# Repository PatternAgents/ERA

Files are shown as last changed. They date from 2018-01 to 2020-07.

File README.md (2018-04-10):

# ERA Embedded Rack Architecture 
 


This repository contains Open Source Hardware Reference Designs for the Embedded Rack Architecture (ERA),
a new design pattern for the interconnection and packaging of Modular Audio/Video equipment.

The Embedded Rack Architecture (ERA) is a new, 
Open Source Hardware (OSHW) specification for 
Modular Audio/Video equipment that is being co-developed by a number of
cooperating companies and individuals in the audio field,
and is backward compatible with the Eurorack specification (aka Legacy Eurorack). 

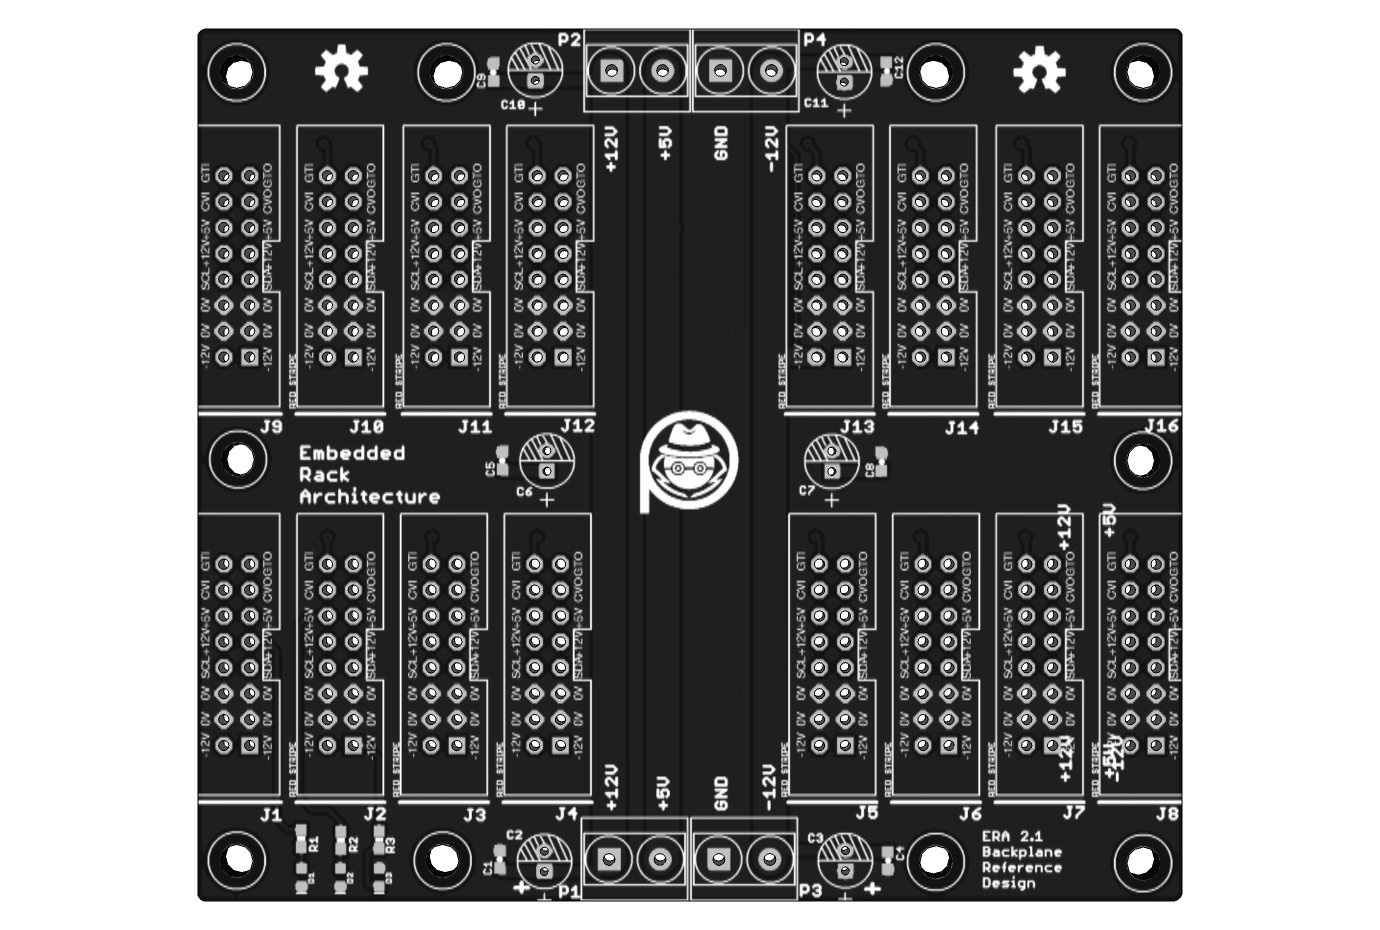
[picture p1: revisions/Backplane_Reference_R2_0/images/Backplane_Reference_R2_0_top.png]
Embedded Rack Architecture (ERA) Backplane Reference Design


For more information, please see the [ERA Wiki](https://github.com/patternagents/ERA/wiki)!

If you'd like to be involved in the development of the new 
Embedded Rack Architecture (ERA) specifications and reference designs,
then please contact us at :  [PatternAgents](https://patternagents.com/store)

-----------------------------------------------------

Eurorack (Legacy) References and Articles

[Doepfer- Eurorack ](http://www.doepfer.de/a100_man/a100m_e.htm)

[Wikipedia-Doepfer](https://en.wikipedia.org/wiki/Doepfer_A-100)

[SDIY Info](https://www.sdiy.info/w/Eurorack)

-----------------------------------------------------

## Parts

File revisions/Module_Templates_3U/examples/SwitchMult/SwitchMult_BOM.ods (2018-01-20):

Qty | Value | Device | Package | Parts | MFR Part Number
5 | 510 | RESISTORPTH-1/4W | AXIAL-0.4 | R1, R2, R3, R4, R5 | MF1/4LCT52R511J
1 | ERA-SHROUD | ERA-SHROUD | ERA | J1 | 302-S161
 | LP4EE1PBCTG | LP4EE1PBCTx | LP4EE1PBCTx | SW1 | LP4EE1PBCTx
 | LP4EE1PBCTG | LP4EE1PBCTx | LP4EE1PBCTx | SW2 | LP4EE1PBCTx
 | LP4EE1PBCTG | LP4EE1PBCTx | LP4EE1PBCTx | SW3 | LP4EE1PBCTx
5 | LP4EE1PBCTG | LLP4EE1PBCTx | LP4EE1PBCTx | SW4 | LP4EE1PBCTx
7 | PJ301_THONKICONN6 | PJ301_THONKICONN6 | WQP_PJ_301M6 | P1, P2, P3, P4, P5, P6, P7 | WQP_PJ_301M6

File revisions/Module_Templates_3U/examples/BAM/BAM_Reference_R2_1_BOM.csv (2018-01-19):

Qty | Value | Device | Package | Parts | Description | MPN | PROD_ID | VALUE
2 | 1K | RESISTOR0603 | 0603-RES | R2, R4 | Resistor
2 | 100K | RESISTOR0603 | 0603-RES | R1, R6 | Resistor
2 | 4K7 | RESISTOR0603 | 0603-RES | R3, R5 | Resistor
2 | BSS138W-7-F | SMD-MOSFET-N-CH-50V-200MA-BSS138W-7-F(SOT-23) | SOT-23 | Q1, Q2 | 305030000 | BSS138W-7-F |  | BSS138W-7-F
2 | ERA-SHROUD | ERA-SHROUD | ERA | ERA, EURO | Embedded Rack Backplane Connector
6 | JACK-3_5MM-MONO-SW-MJ_3502 | JACK-3_5MM-MONO-SW-MJ_3502 | MJ-3502 | CV_IN, CV_OUT, CV_THRU, GATE_IN, GATE_OUT, GATE_THRU | Jack, 3.5mm, RIght Angle, Though-Hole
1 | LED-RG-CC-PTH-G18500 | LED-RG-CC-PTH-G18500 | LED-RG-PANEL | LED1 | LED Red/Green Common Cathode Pin Through Hole

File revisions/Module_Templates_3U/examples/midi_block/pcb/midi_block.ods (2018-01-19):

Qty | Value | Device | Package | Parts | Description | PROD_ID
3 |  | JMP-3-NO-PTH | JMP-3-NO-PTH-2.54 | RXD, TXD, VCC | Three Terminal Jumper - Normally Open
2 | 100nf | CAP0603-CAP | 0603-CAP | C1, C3 | Capacitor
1 | 10uf | CAP0603-CAP | 0603-CAP | C2 | Capacitor
2 | 1K | R-US_R0603 | R0603 | R2, R3 | RESISTOR, American symbol
1 | 1N4148 | DIODE-SOD323-W | SOD323-W | D1 | DIODE
7 | 220 | R-US_R0603 | R0603 | R1, R4, R5, R6, R7, R8, R9 | RESISTOR, American symbol
1 | 6N137SMT | 6N137SMT | DIL8-SMD | OPTO | MOTOROLA OPTO COUPLER
1 | 74HC7014D | 74HC7014D | SOIC-14 | U1 | The 74HC7014 is a hex buffer with precision Schmitt-trigger inputs. | IC-12527
3 | DIN-5-MIDI-PTH-RA | DIN-5-MIDI-PTH-RA | DIN-5-PTH-RA-SUPPORT | MIDI_IN, MIDI_OUT, MIDI_THRU | DIN-5 (MIDI) connector
1 | ERA-SHROUD | ERA-SHROUD | ERA | ERA | EuroRack2 - Backplane Connector
1 | LED-RG-CC-PTH-G18500 | LED-RG-CC-PTH-G18500 | LED-RG-PANEL | LED1 | LED Red/Green Common Cathode Pin Through Hole
2 | MOUNT-HOLE3,2S | MOUNT-HOLE3,2S | 3,2,SMALL | H1, H2 | MOUNTING HOLE with drill center marker
1 | PA_FTDI_BASIC_PERIPHERAL | PA_FTDI_BASIC_PERIPHERAL | PA_PMOD_SIL_MALE | FTDI | PatternAgents FTDI UART BASIC Pattern
4 | PCB-MB-SIDE | PCB-MB-SIDE | PCB-MB-01-SIDE | U$1, U$2, U$3, U$4 | Mounting Block Hardware

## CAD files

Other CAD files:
revisions/Module_Templates_3U/examples/BAM/eagleUp/BAM_Reference_R2_1.skp
revisions/Module_Templates_3U/examples/SwitchMult/eagleUp/SwitchMult.skp
revisions/Module_Templates_3U/examples/midi_block/pcb/eagleUp/midi_block.skp

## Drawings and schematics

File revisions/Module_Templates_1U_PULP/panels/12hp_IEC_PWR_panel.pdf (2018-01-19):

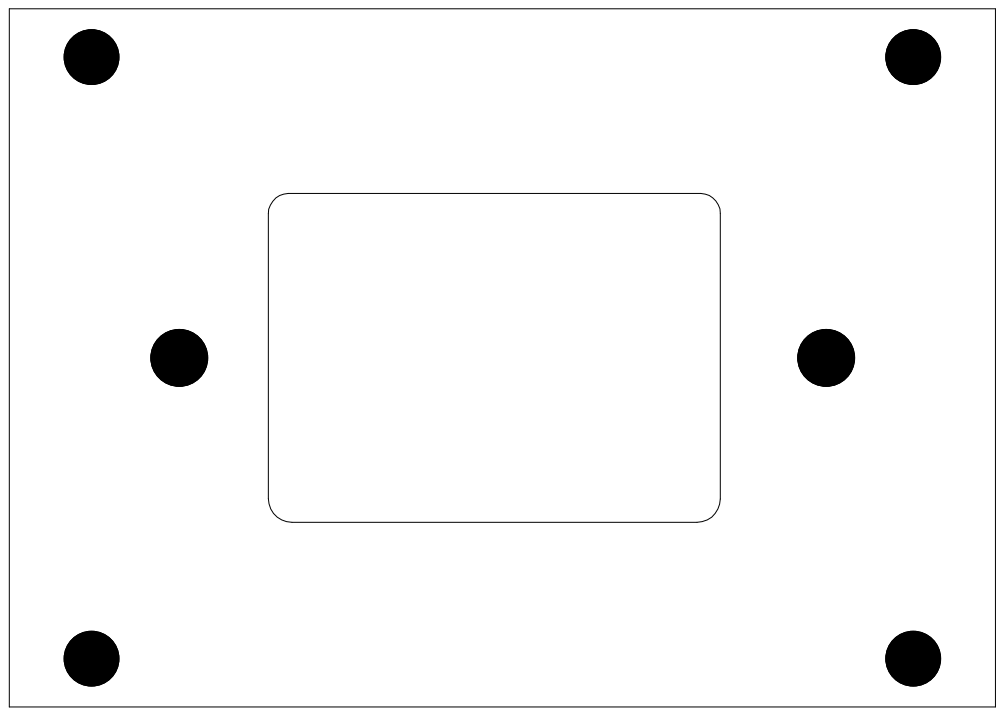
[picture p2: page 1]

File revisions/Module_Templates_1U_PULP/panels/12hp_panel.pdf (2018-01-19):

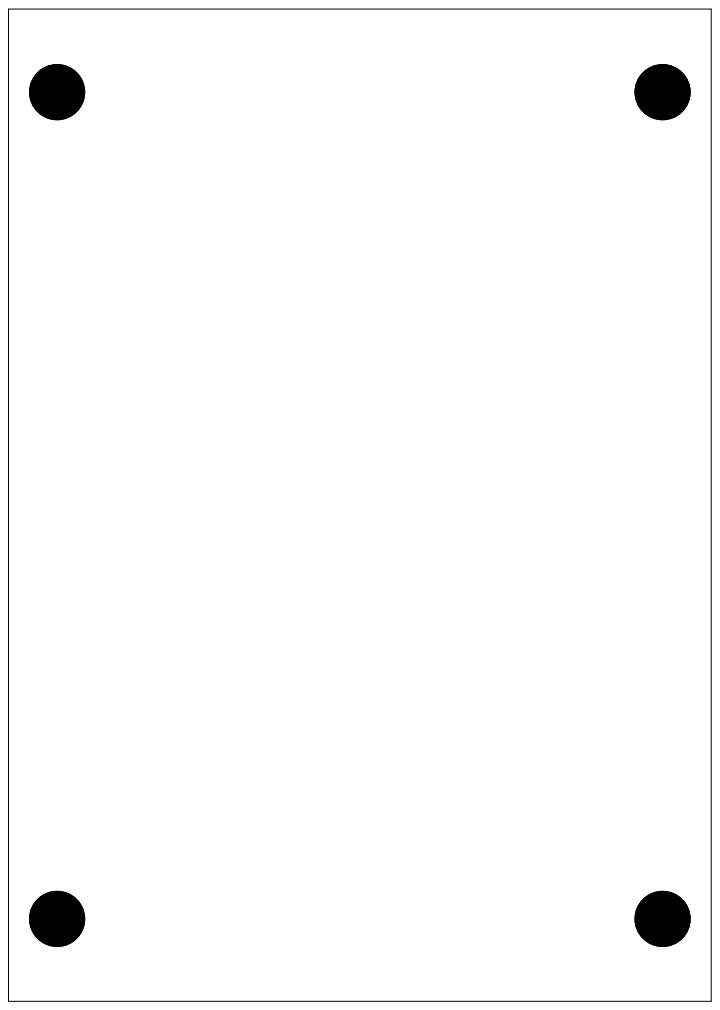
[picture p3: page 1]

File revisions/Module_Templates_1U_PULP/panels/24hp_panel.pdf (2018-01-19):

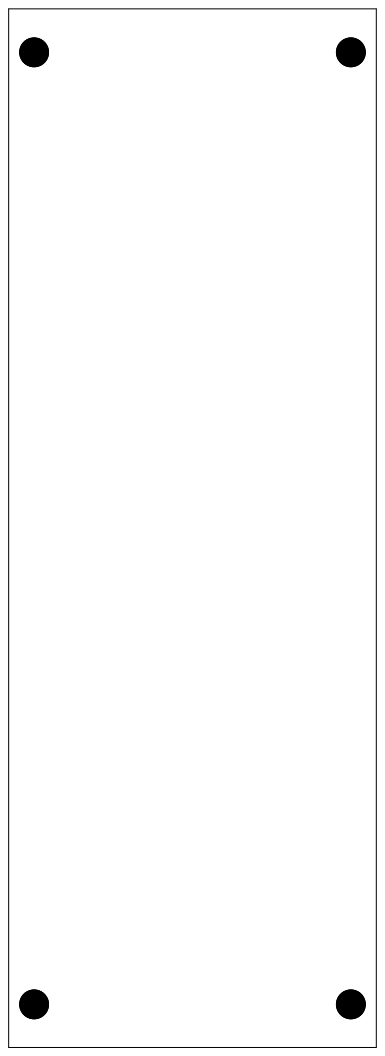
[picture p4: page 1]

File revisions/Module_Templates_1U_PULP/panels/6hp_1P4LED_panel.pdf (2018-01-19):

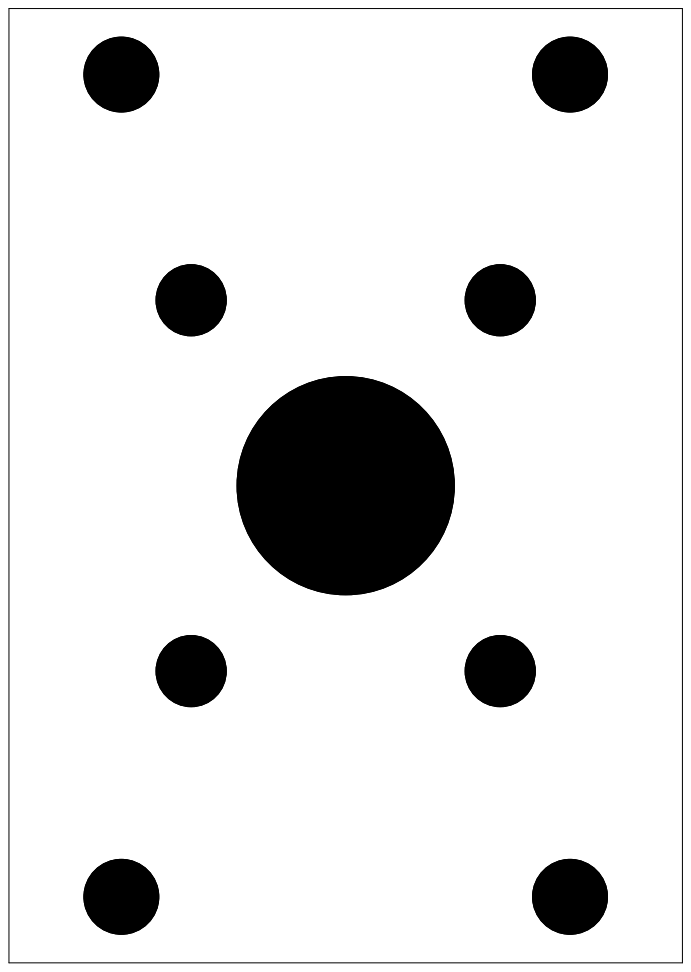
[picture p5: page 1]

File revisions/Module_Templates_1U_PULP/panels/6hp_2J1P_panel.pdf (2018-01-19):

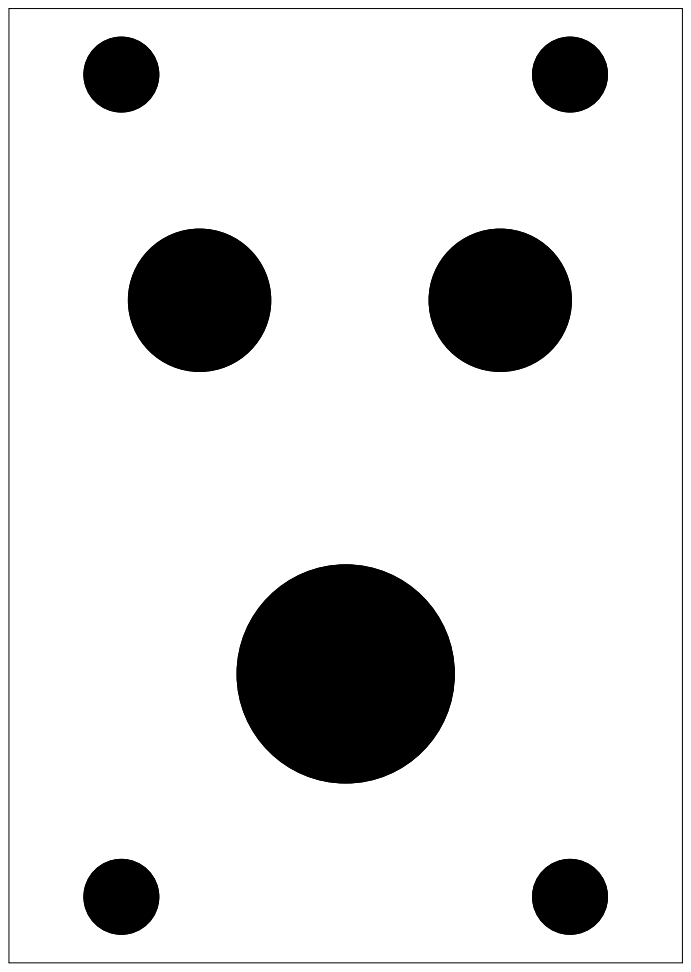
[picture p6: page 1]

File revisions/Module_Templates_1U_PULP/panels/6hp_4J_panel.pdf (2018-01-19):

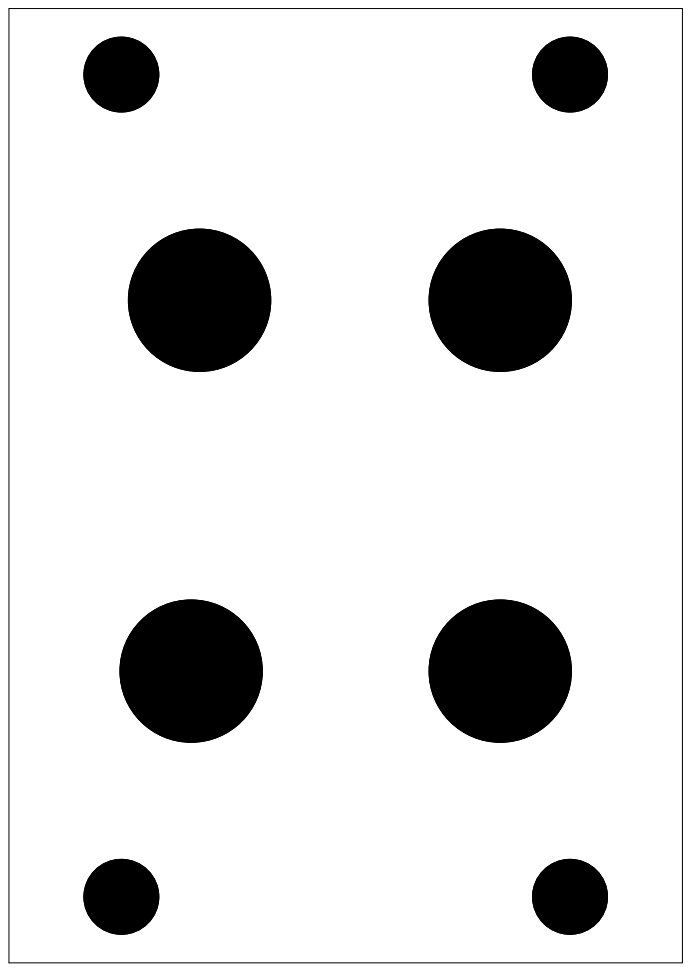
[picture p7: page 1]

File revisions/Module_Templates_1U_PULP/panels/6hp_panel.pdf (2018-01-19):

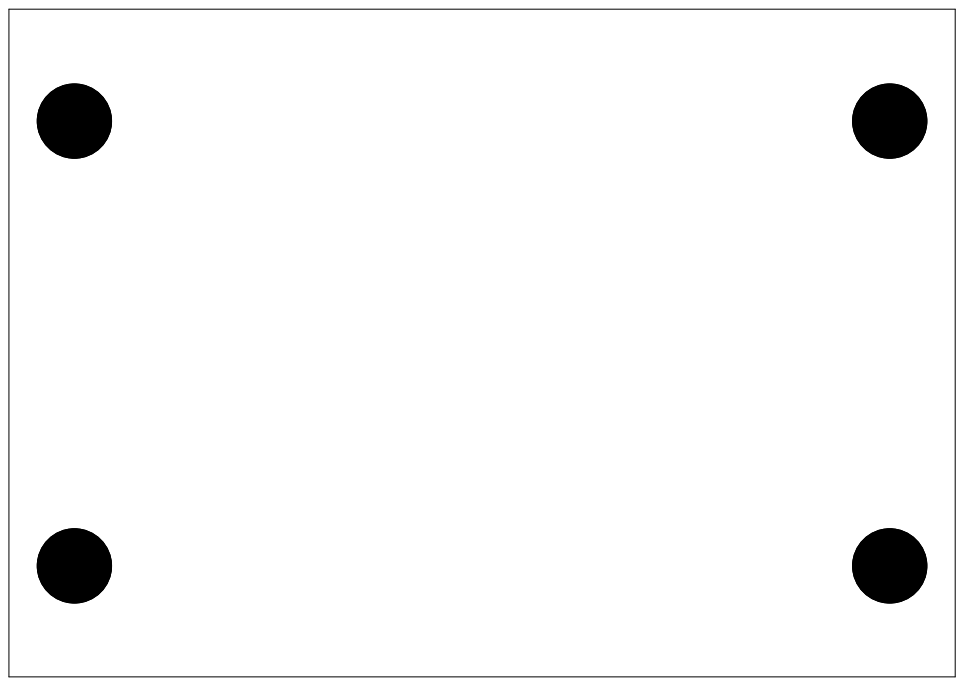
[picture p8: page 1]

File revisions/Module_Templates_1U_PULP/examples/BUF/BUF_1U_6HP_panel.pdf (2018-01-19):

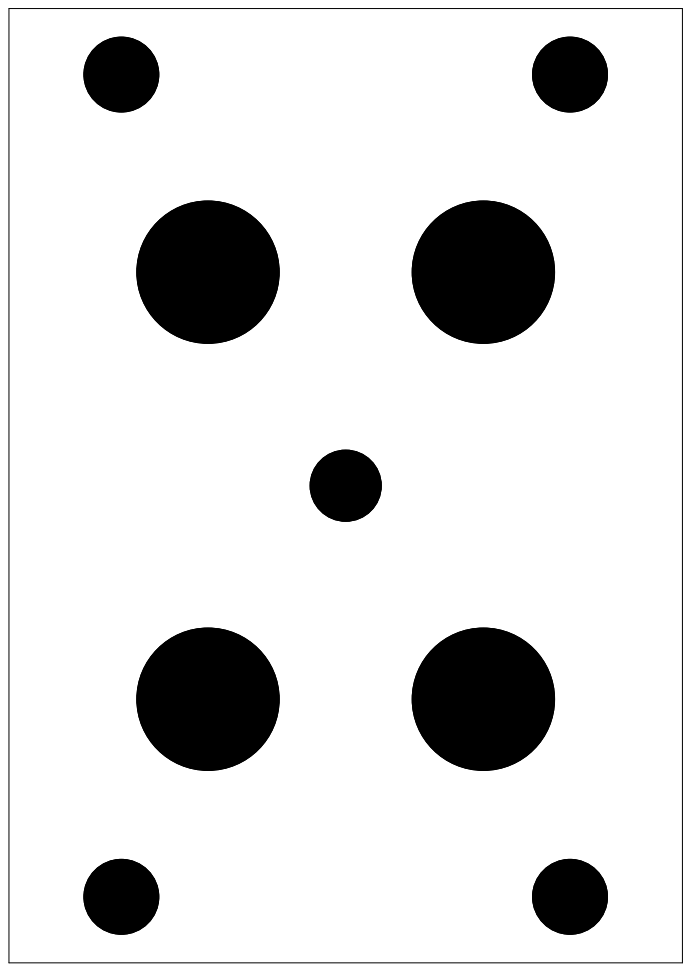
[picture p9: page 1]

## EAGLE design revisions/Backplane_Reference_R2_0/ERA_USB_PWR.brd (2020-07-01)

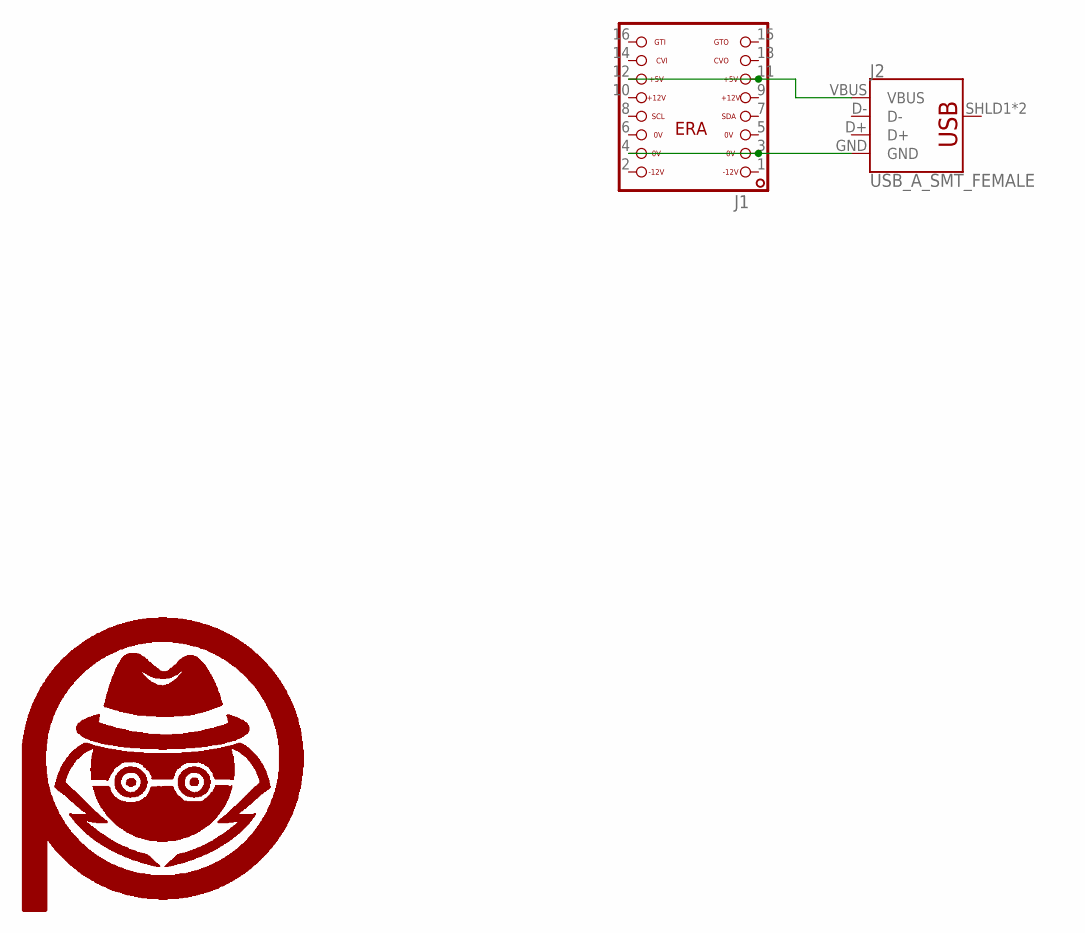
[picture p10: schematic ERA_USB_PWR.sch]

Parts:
J1: ERA_16PIN-NOSILK; ERA-16-NOSILK
J2: USB_A_SMT_FEMALE; USB-A-S-SILK-FEMALE
U$1, U$2: PA_LOGO_SYMSMALL; PA_LOGO_AGENT_SMALL_SYM

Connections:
GND: J1.3, J1.4, J2.GND
unnamed: J1.11, J1.12, J2.VBUS

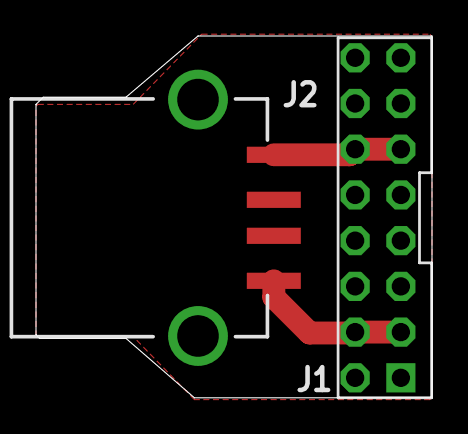
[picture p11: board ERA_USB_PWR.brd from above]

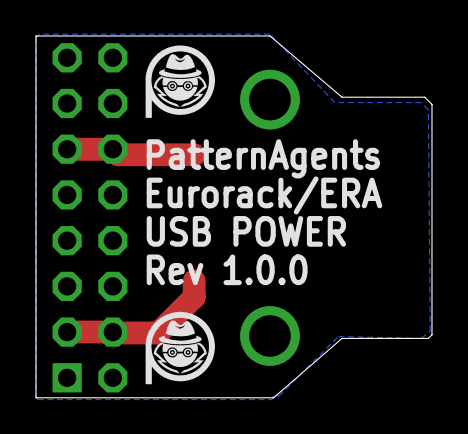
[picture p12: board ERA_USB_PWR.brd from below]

Board: 2 copper layers, 22.0 x 20.1 mm, 4 parts (2 on the bottom side), 2 nets.

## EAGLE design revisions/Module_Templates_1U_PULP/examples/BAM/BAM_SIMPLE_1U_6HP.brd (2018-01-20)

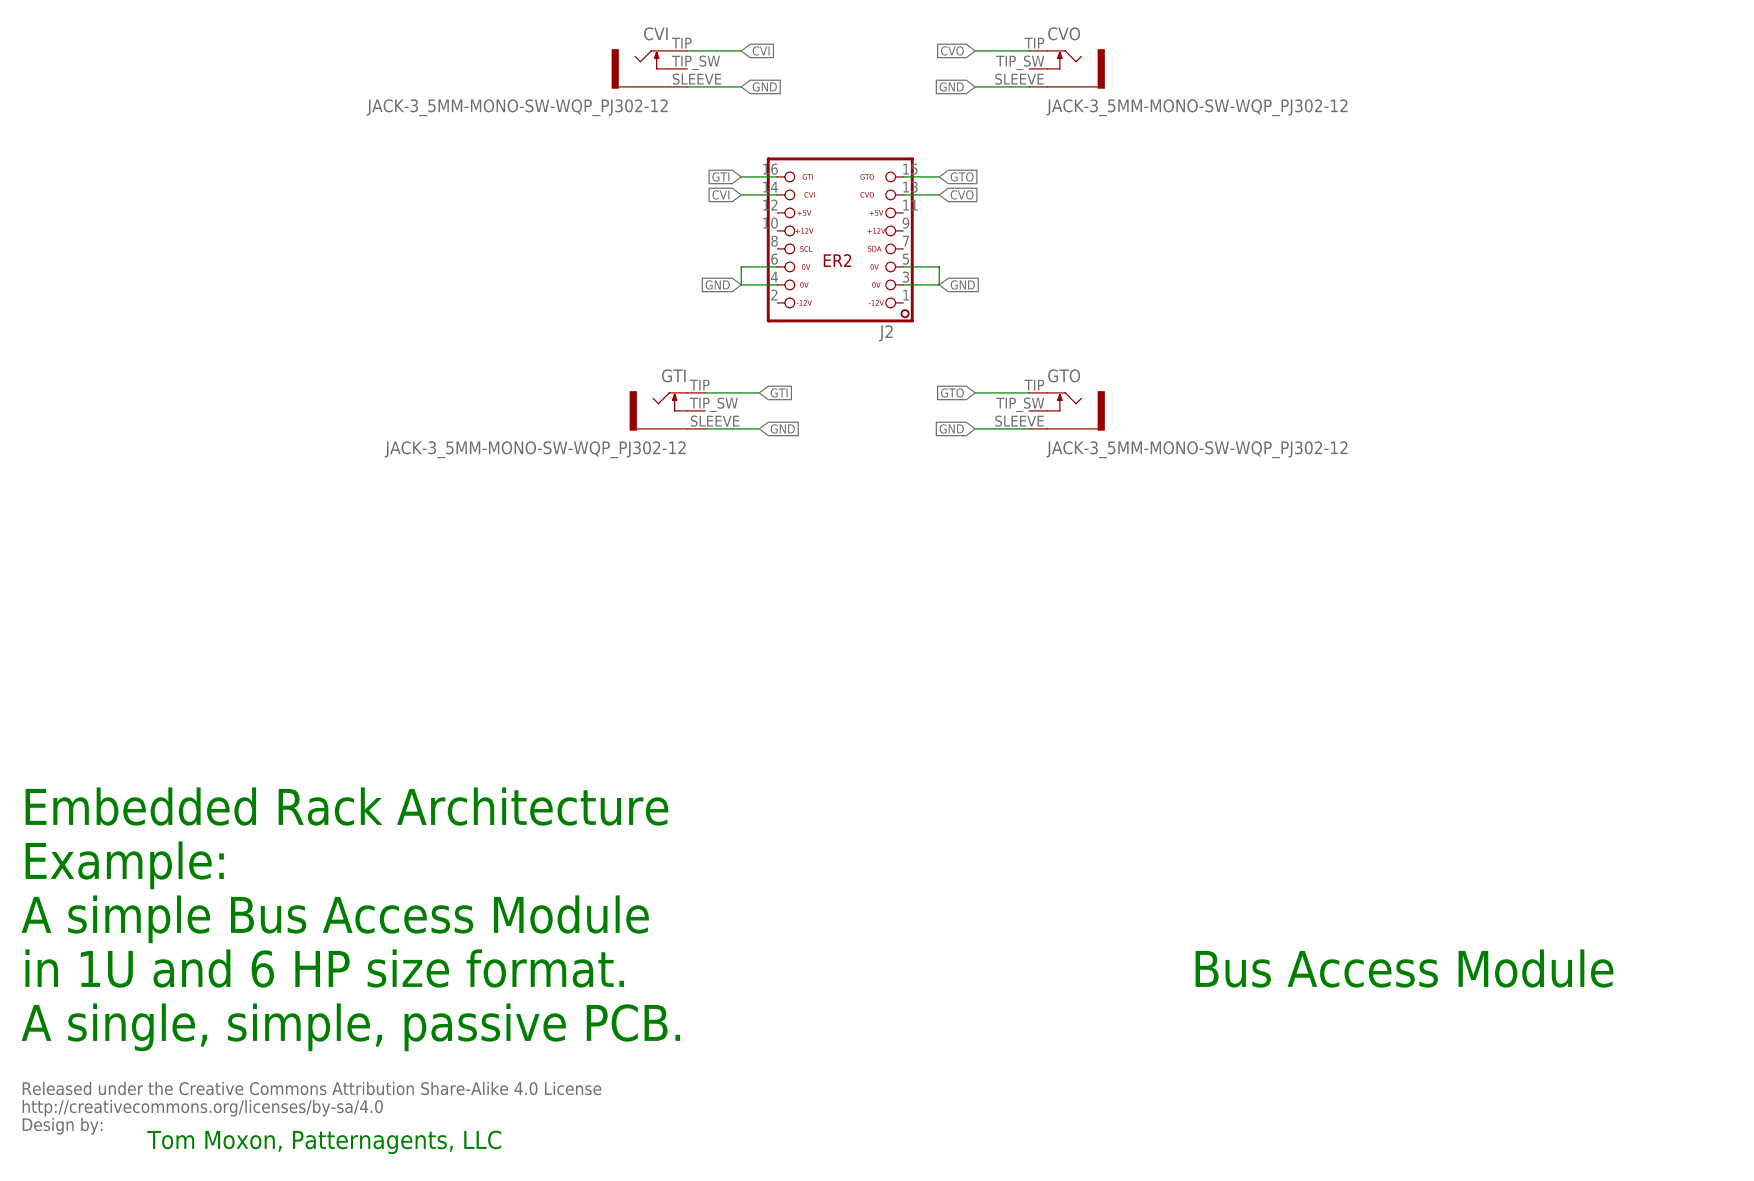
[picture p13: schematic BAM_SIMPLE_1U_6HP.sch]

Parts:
CVI: JACK-3_5MM-MONO-SW-WQP_PJ302-12; WQP_PJ301M-12
CVO: JACK-3_5MM-MONO-SW-WQP_PJ302-12; WQP_PJ301M-12
GTI: JACK-3_5MM-MONO-SW-WQP_PJ302-12; WQP_PJ301M-12
GTO: JACK-3_5MM-MONO-SW-WQP_PJ302-12; WQP_PJ301M-12
J2: ER2-SHROUD; ER2
TOMMOXON: BY_CC_SA_TEXTNULL; NULL_SYM

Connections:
CVI: CVI.TIP, J2.14
CVO: CVO.TIP, J2.13
GND: CVI.SLEEVE, CVO.SLEEVE, GTI.SLEEVE, GTO.SLEEVE, J2.3, J2.4, J2.5, J2.6
GTI: GTI.TIP, J2.16
GTO: GTO.TIP, J2.15

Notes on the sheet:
Bus Access Module
Embedded Rack Architecture Example: A simple Bus Access Module in 1U and 6 HP size format. A single, simple, passive PCB.
Tom Moxon, Patternagents, LLC

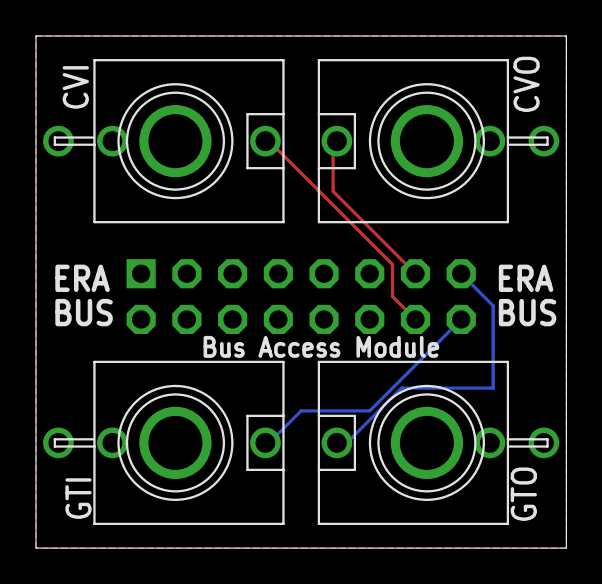
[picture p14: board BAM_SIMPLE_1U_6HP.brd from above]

Board: 2 copper layers, 29.5 x 28.4 mm, 6 parts (1 on the bottom side), 5 nets.

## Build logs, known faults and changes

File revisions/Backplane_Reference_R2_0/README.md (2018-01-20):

## ERA ##

Embedded Rack Architecture 2.0 Specifications and Reference Designs 

-----------------------------------------------------

This repository contains Open Source Hardware Reference Designs for ERA 2.0

-----------------------------------------------------

The Backplane Reference is a simple, passive, fourteen (14) slot Backplane in a compact form factor.
The Embedded Rack Architecture supports the following signals:

* Ground (GND)        (4 pins)
* +12V DC (1A min)    (2 pins)
* -12V DC (.5A min)   (2 pins)
* +5V DC (1A min)     (2 pins)
* Control Voltage In  (1 pin)   (-5.0 to 5.0 volts)
* Control Voltage Out (1 pin)   (-5.0 to 5.0 volts)
* Gate In             (1 pin)   (0.0 - 5.0 volts)
* Gate Out            (1 pin)   (0.0 - 5.0 volts)
* I2C SDA             (1 pin)   (0.0 - 5.0 volts)
* I2C SCL             (1 pin)   (0.0 - 5.0 volts)

Because a reverse polarity power connection can short the SDA & SCL pins to the +12V DC pins,
the ERA specification includes a simple N-Channel Mosfet circuit that provides both Level Shifting 
(for lower voltage CPU interfaces) and over-voltage/reverse-voltage protection on the ERA I2C Signals (SDA & SCL). 
The circuit is described in the ERA Module Reference Design.

-----------------------------------------------------
For more information, please see the [ERA Wiki](https://github.com/patternagents/ERA/wiki)!
-----------------------------------------------------

Embedded Rack 2.0 Backplane Reference Design

-----------------------------------------------------

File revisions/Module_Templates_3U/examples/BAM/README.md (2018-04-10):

# Bus Access Module (BAM)



Bus Access Module - ERA Reference Design

Format : ERA / Eurorack 

Height : 3U 

Width: 3HP

Depth : 1.0 cm

Power : +12V 40mA, -12V 40mA

Jacks : 3.5mm mono

The Bus Access Module (BAM) is used as a passive break out board for 
ERA backplane signals to the patchbay/front panel.
It includes a legacy Eurorack Connector as well as an ERA connector
for compatibility with other/older backplanes and modules.
A buffered, dual color LED is used as an optional CV/Gate activity indicator. 

-----------------------------------------------------

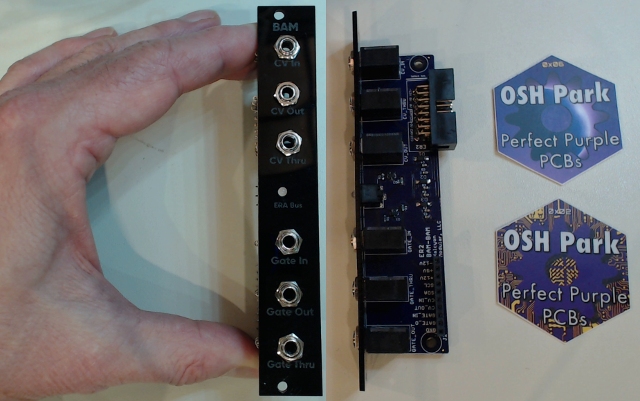
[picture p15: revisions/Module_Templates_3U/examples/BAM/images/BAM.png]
Bus Access Module Reference Design


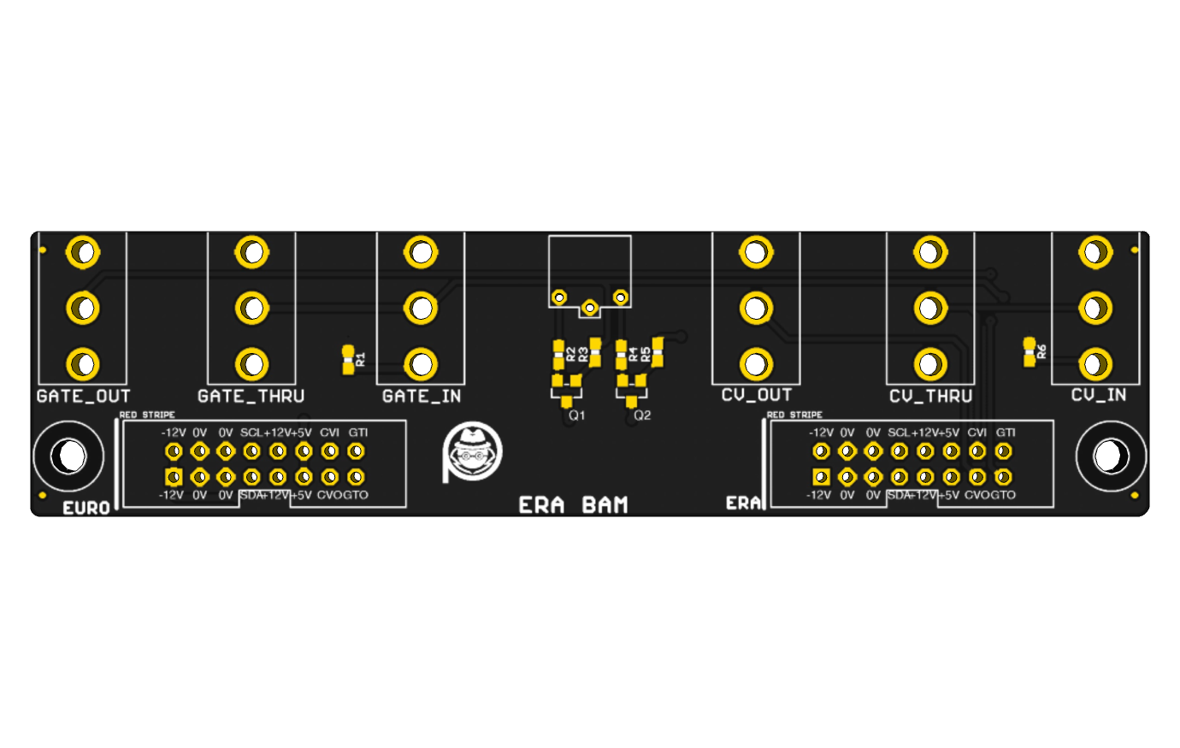
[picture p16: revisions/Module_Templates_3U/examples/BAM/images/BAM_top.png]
Bus Access Module Reference Design


-----------------------------------------------------

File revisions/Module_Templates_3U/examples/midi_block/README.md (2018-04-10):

# midi_block



Format : ERA / Eurorack

Height : 3U 

Width: 6HP

Depth : 1.0 cm

Power : +5V 35mA

Jacks : DIN 5-PIN

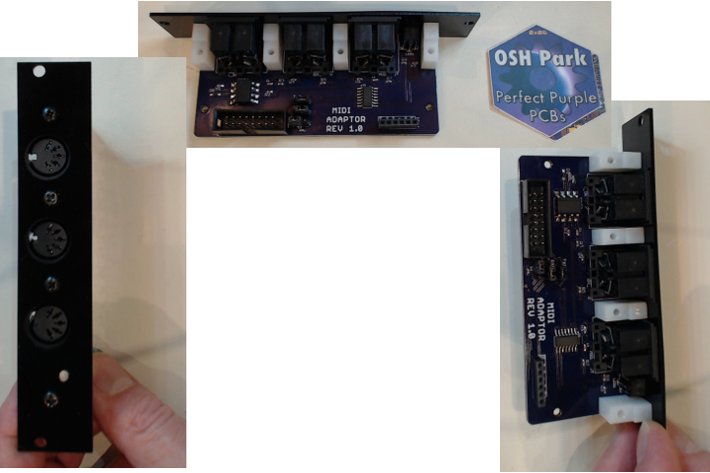
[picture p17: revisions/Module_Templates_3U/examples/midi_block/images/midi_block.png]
Embedded Rack Architecture (ERA) MIDI Reference Design


-----------------------------------------------------
This repository contains Open Source Hardware Reference Designs for Embedded Rack Architecture (ERA)
that anyone can use or fabricate for themselves.

For more information, please see the [ERA Wiki](https://github.com/halcyonmodular/ERA/wiki)!

Embedded Rack Architecture (ERA) is a new, Open Source Hardware (OSHW) specification for 
Modular Audio/Video equipment that is being co-developed by a number of
cooperating companies and individuals in the audio field,
and is completely backward compatible with Eurorack (Legacy). 

-----------------------------------------------------

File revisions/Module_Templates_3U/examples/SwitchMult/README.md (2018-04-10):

# SwitchMult



Format : ERA / Eurorack

Height : 3U 

Width: 4HP

Depth : 1.0 cm

Power : +12V 35mA

Jacks : 3.5mm Jacks (Thonkiconn PJ301M-12)

A simple, passive, "Switched Multiple" design for ERA/Eurorack. 
Four(4) latching, LED illuminated, pushbutton switches, 
control up to four (4) input/outputs,
that are routed to an internal bus.
The four inputs (P1-P4) are "normalized" to the ERA bus signals as follows:

1) ERA Bus Gate In  (Green)
2) ERA Bus CV In    (Red)
3) ERA Bus Gate Out (Blue)
4) ERA Bus CV Out   (Yellow)

When connected to an ERA backplane, those Bus signals can be routed to other
"Switched Multiple" modules, or other ERA audio/video modules.

Embedded Rack Architecture (ERA) Switched Multiple Reference Design

-----------------------------------------------------
This repository contains Open Source Hardware Reference Designs for Embedded Rack Architecture (ERA)
that anyone can use or fabricate for themselves.

For more information, please see the [ERA Wiki](https://github.com/halcyonmodular/ERA/wiki)!

Embedded Rack Architecture (ERA) is a new, Open Source Hardware (OSHW) specification for 
Modular Audio/Video equipment that is being co-developed by a number of
cooperating companies and individuals in the audio field,
and is completely backward compatible with Eurorack (Legacy). 

-----------------------------------------------------

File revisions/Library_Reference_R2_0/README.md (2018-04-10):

## ERA 2.0 ##



Embedded Rack 2.0 Specifications and Reference Designs 

-----------------------------------------------------

This repository contains Open Source Hardware Reference Designs for Embedded Rack 2.0

-----------------------------------------------------

For more information, please see the [ER2 Wiki](https://github.com/patternagents/ER2/wiki)!

Embedded Rack 2.0 Backplane Reference Design

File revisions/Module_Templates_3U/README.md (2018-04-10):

# ERA Templates #



Design Pattern Templates for ERA modules

-----------------------------------------------------

This repository contains Open Source Hardware Reference Designs for Embedded Rack Architecture

Backplane Reference Design

Bus Access Module Reference Design

Library Reference

Module Reference Design

-----------------------------------------------------

For more information, please see the [ERA Wiki](https://github.com/patternagents/ERA/wiki)!

ERA Backplane Reference Design

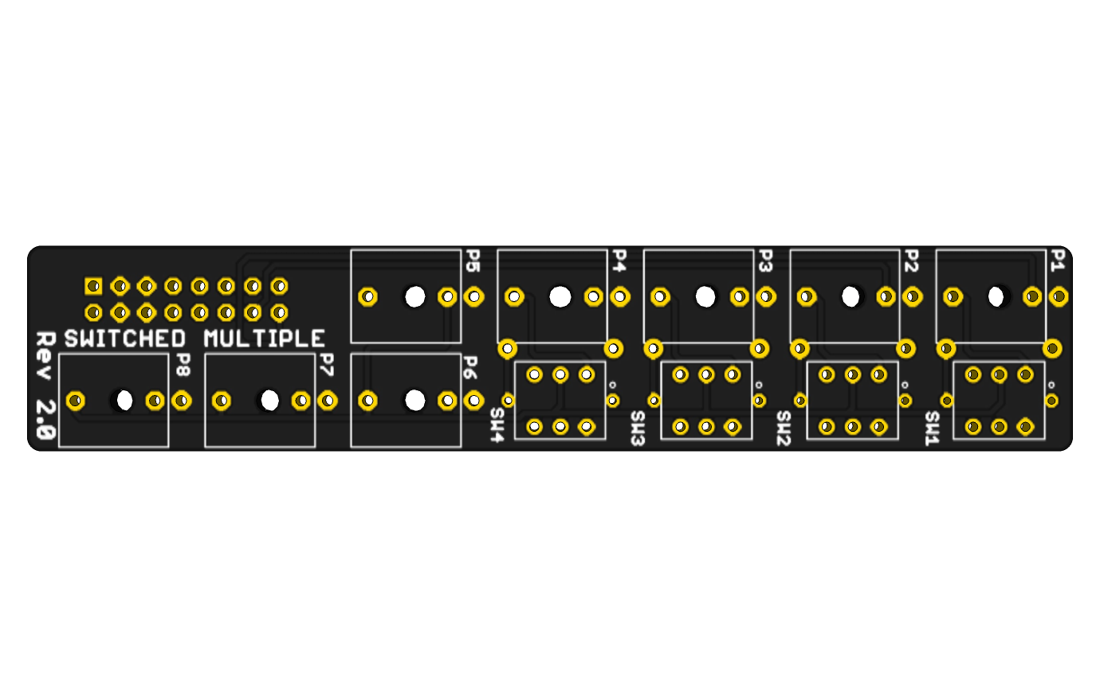
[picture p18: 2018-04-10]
revisions/Module_Templates_3U/examples/SwitchMult/images/SwitchMult_top.png

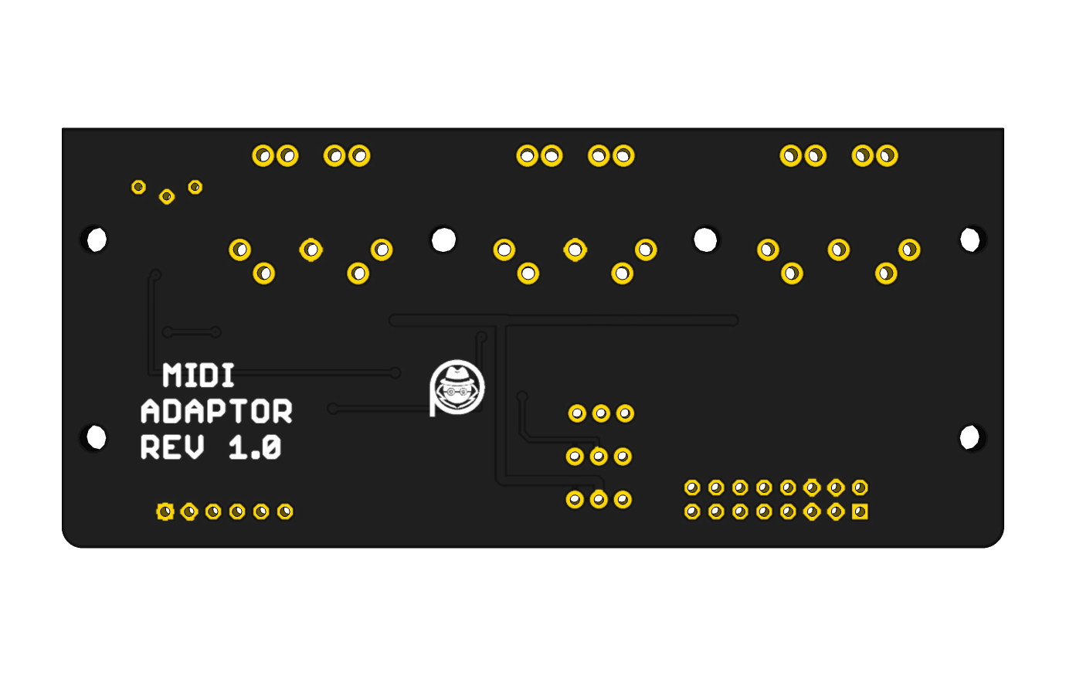
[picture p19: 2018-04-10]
revisions/Module_Templates_3U/examples/midi_block/pcb/images/midi_block_bot.png

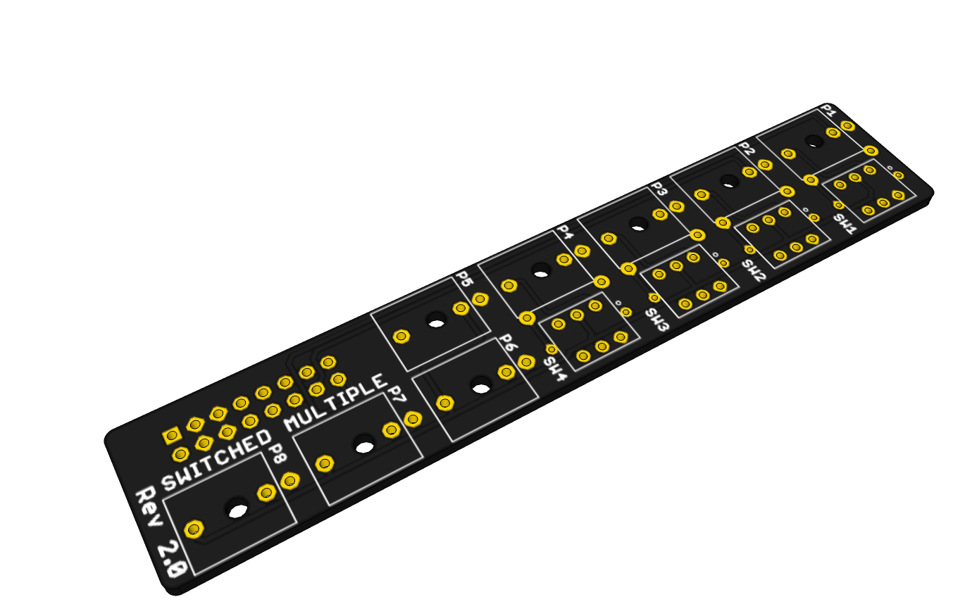
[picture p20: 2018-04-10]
revisions/Module_Templates_3U/examples/SwitchMult/images/SwitchMult_iso.png

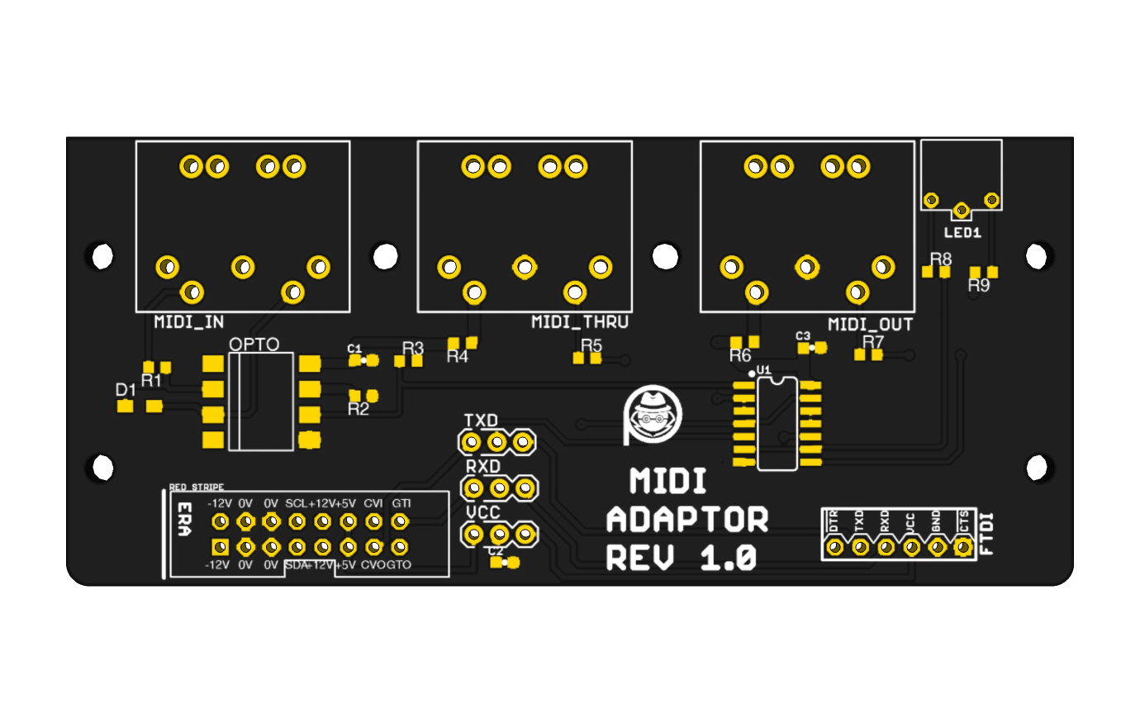
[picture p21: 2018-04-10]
revisions/Module_Templates_3U/examples/midi_block/pcb/images/midi_block_top.png

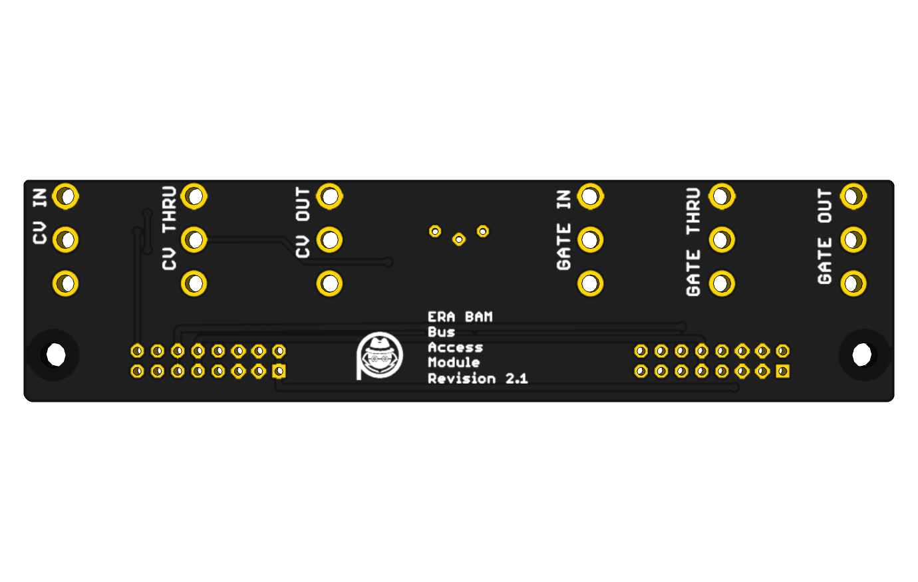
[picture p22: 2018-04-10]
revisions/Module_Templates_3U/examples/BAM/images/BAM_bot.png

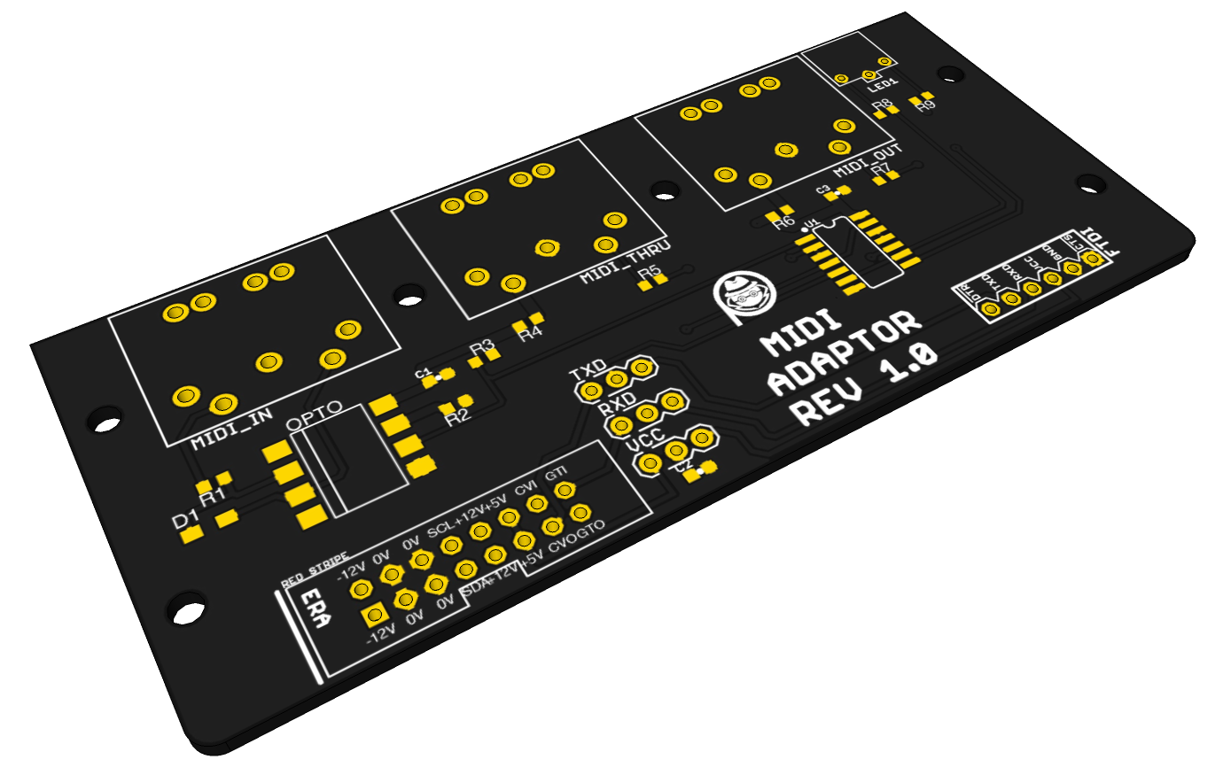
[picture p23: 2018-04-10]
revisions/Module_Templates_3U/examples/midi_block/pcb/images/midi_block_iso.png

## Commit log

2018-01-19 initial version
    [10hp_board.brd, 10hp_board.sch, 12hp_IEC_PWR_panel.brd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]
2018-01-20 Update Backplane Reference
    [BAM_Reference_R2_0.brd, BAM_Reference_R2_0.sch, BAM_Reference_R2_1_1.brd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]
2018-01-20 update backplane images
    [BUF_1U_6HP_fpb.brd, Backplane_Compact_R2_1.brd]
2018-04-10 4/10 update
    [BAM_Reference_R2_0.brd, BAM_Reference_R2_0.sch, BAM_Reference_R2_1.brd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]
2020-07-01 Enlarge SwitchMult Front panel holes for easier assembly/operation
    [12hp_IEC_PWR_panel.brd, 12hp_IEC_PWR_panel.sch, 12hp_board.brd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]

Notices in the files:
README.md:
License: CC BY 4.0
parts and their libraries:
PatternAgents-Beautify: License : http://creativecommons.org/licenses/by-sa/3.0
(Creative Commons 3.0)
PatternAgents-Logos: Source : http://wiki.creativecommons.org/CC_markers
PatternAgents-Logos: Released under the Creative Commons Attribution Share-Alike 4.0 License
